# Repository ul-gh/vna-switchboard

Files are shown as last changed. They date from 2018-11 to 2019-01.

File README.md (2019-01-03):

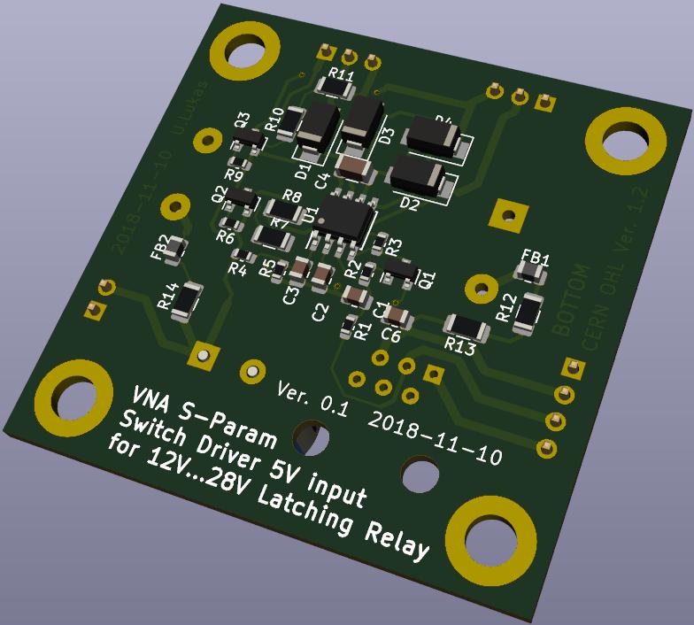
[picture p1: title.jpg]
Title Image


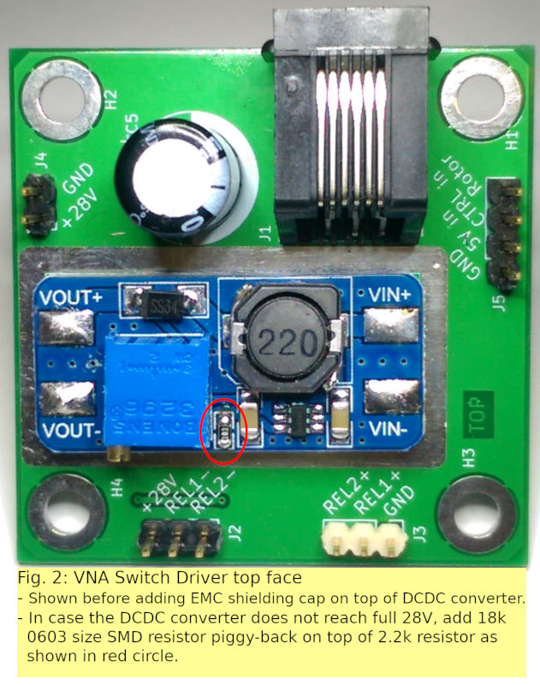
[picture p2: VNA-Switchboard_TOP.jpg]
Image VNA-Switchboard TOP face


# VNA-Switchboard FAN3241
KiCad project files for PCB driving a 12V...28V latching relay
from a single 5V voltage source, control is a high/low input signal.

Using an MT3608 step-up DCDC converter input current-limited
to less than 100 mA, timing and protection circuitry integrated
into FAN3241 driver IC and RF/EMC shielding provision for the
step-up coverter, this is designed for driving the direction
switch of a VNA S-parameter test set.

The input is a 6P6 western socket pinning compatible to the
DG8SAQ VNWA3. When this input is connected, no additional power
supply or control signals are required.

Schematic PDF: [VNA-Switchboard_FAN3241.pdf](VNA-Switchboard_FAN3241.pdf)

Additional instructions: Most if not all MT3608 DCDC converter boards sold
today require the following bug fix if medium output voltages are to be set:

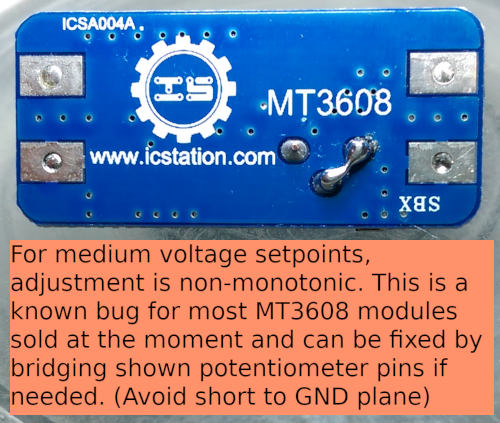
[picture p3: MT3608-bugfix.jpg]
MT3608 bug fix


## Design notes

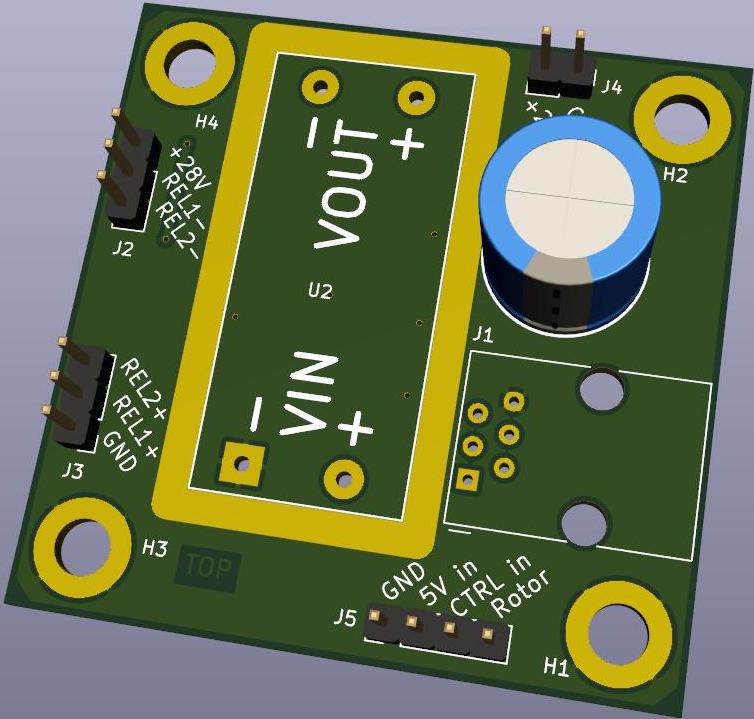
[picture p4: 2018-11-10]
preview2.jpg

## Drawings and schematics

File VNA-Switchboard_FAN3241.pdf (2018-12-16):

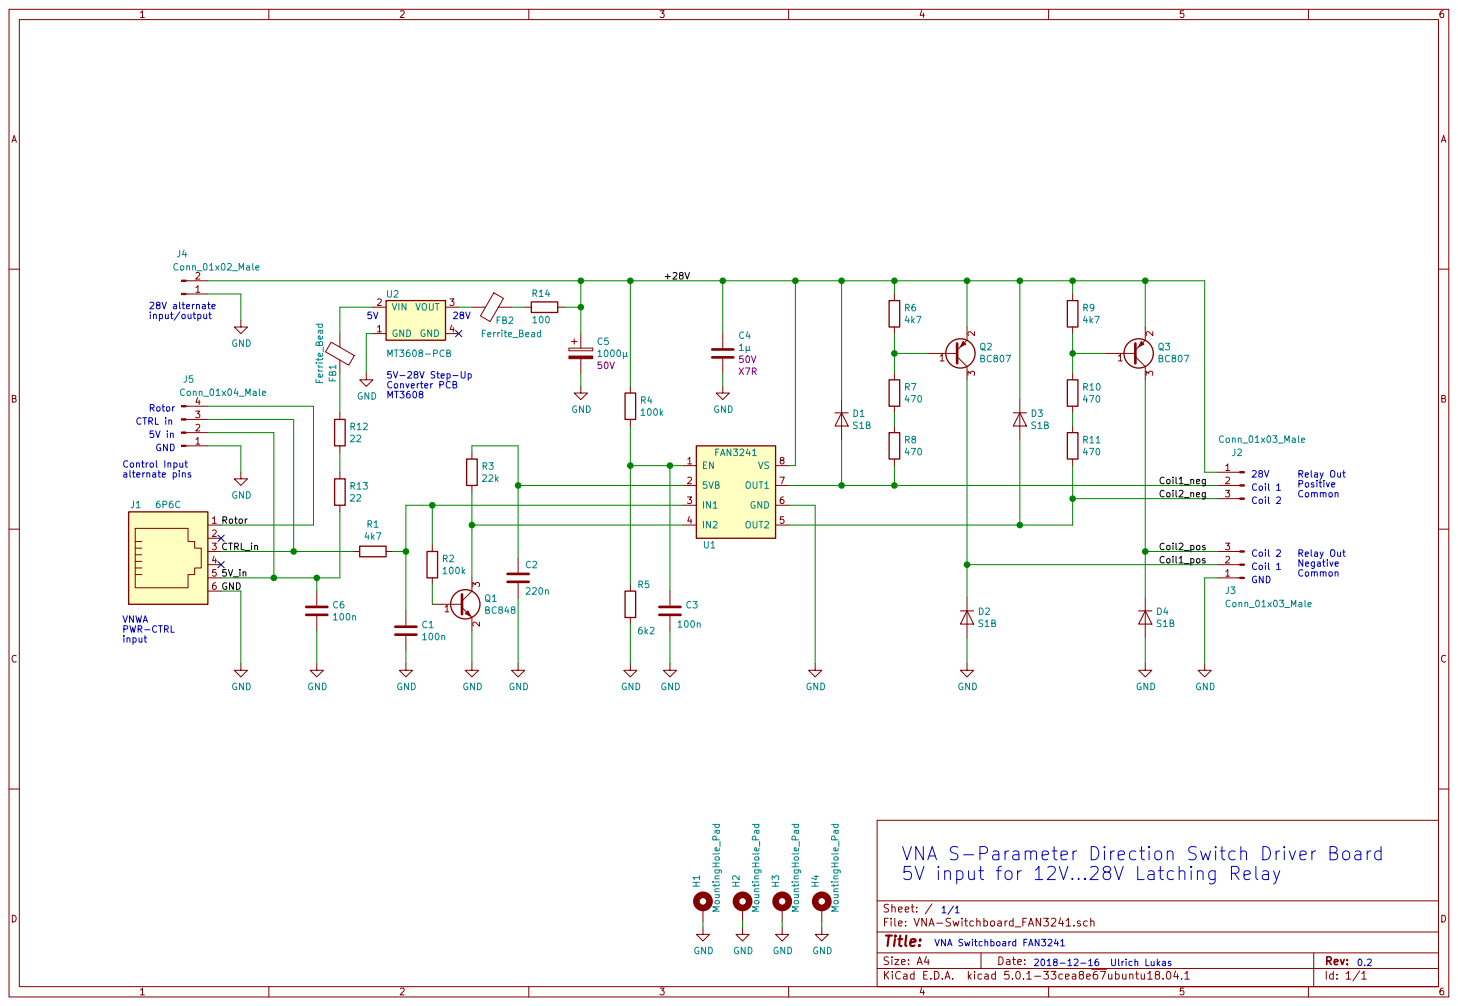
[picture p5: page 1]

5V input for 12V...28V Latching Relay

File: VNA-Switchboard_FAN3241.sch Sheet: /
Id: 1/1 Title:

2018-12-16 Ulrich Lukas VNA Switchboard FAN3241

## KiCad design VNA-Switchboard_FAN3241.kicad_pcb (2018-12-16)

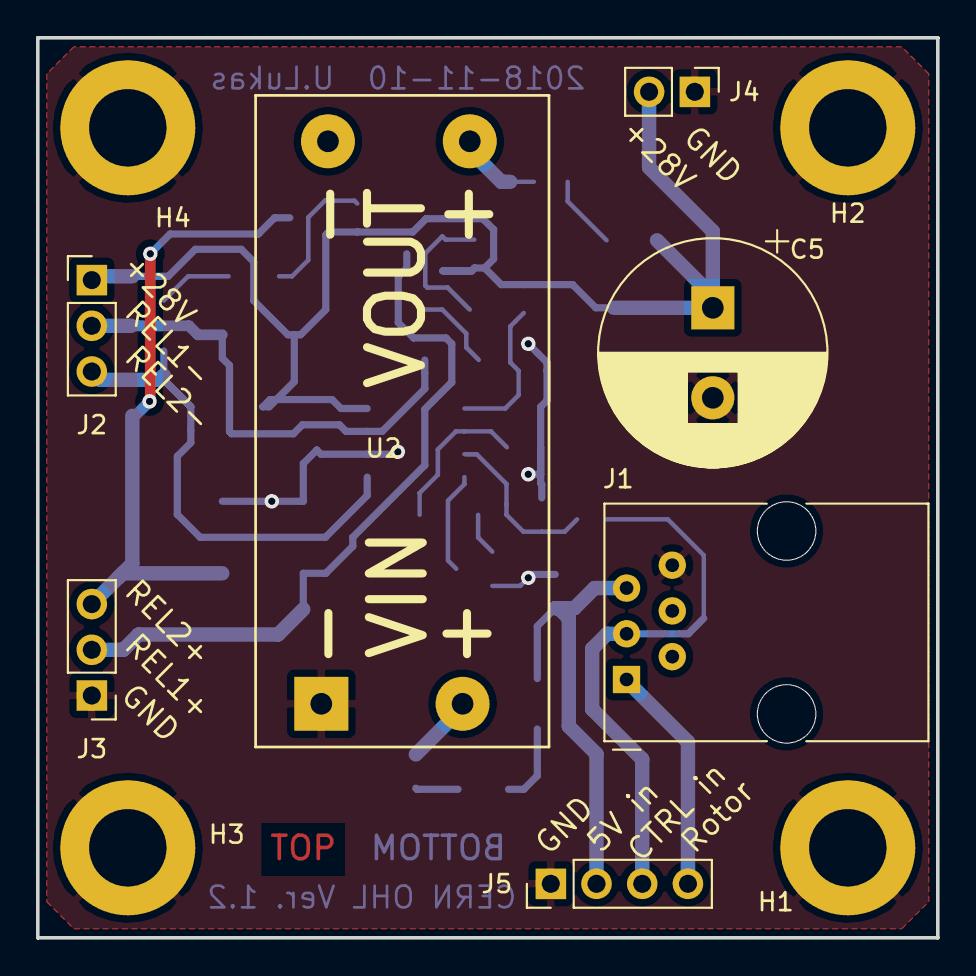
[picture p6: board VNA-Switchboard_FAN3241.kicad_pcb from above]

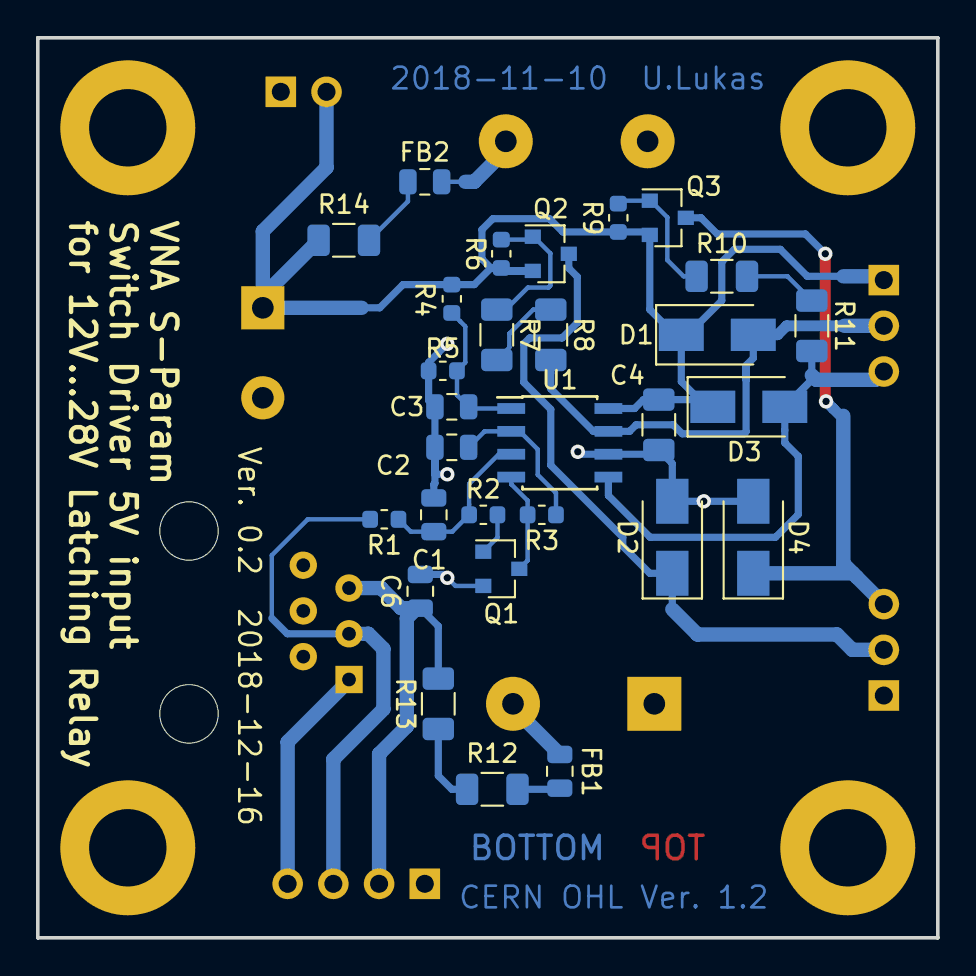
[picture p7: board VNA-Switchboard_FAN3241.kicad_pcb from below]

Board: 2 copper layers, 50.0 x 50.0 mm, 40 parts (29 on the bottom side), 23 nets.

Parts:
C1, C3, C6: 100n; C_0805_2012Metric
C2: 220n; C_0805_2012Metric
C4: 1µ; C_1206_3216Metric
C5: 1000µ; CP_Radial_D12.5mm_P5.00mm
D1, D2, D3, D4: S1B; D_SMA
FB1, FB2: Ferrite_Bead; L_0805_2012Metric
H1, H2, H3, H4: MountingHole_Pad; MountingHole_4.3mm_M4_DIN965_Pad
J1: 6P6C; RJ12_Amphenol_54601
J2, J3: Conn_01x03_Male; PinHeader_1x03_P2.54mm_Vertical
J4: Conn_01x02_Male; PinHeader_1x02_P2.54mm_Vertical
J5: Conn_01x04_Male; PinHeader_1x04_P2.54mm_Vertical
Q1: BC848; SOT-23
Q2, Q3: BC807; SOT-23
R1, R6, R9: 4k7; R_0603_1608Metric
R2, R4: 100k; R_0603_1608Metric
R3: 22k; R_0603_1608Metric
R5: 6k2; R_0603_1608Metric
R7, R8, R10, R11: 470; R_1206_3216Metric
R12, R13: 22; R_1206_3216Metric
R14: 100; R_1206_3216Metric
U1: FAN3241; SOIC-8_3.9x4.9mm_P1.27mm
U2: MT3608-PCB; MT3608_Step-Up_Converter_PCB

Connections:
/5V_in: C6.1, J1.5, J5.2, R13.2
/+28V: C4.1, C5.1, D1.1, D3.1, J2.1, J4.2, Q2.2, Q3.2, R4.1, R6.1, R9.1, R14.2, U1.8
/CTRL_in: J1.3, J5.3, R1.2
/Coil1_neg: D1.2, J2.2, R8.2, U1.7
/Coil1_pos: D2.1, J3.2, Q2.3
/Coil2_neg: D3.2, J2.3, R11.2, U1.5
/Coil2_pos: D4.1, J3.3, Q3.3
/Rotor: J1.1, J5.4
GND: C1.2, C2.2, C3.2, C4.2, C5.2, C6.2, D2.2, D4.2, H1.1, H2.1, H3.1, H4.1, J1.6, J3.1, J4.1, J5.1, Q1.2, R5.2, U1.6, U2.1
unnamed: C1.1, R1.1, R2.1, U1.3
unnamed: C2.1, R3.1, U1.2
unnamed: C3.1, R4.2, R5.1, U1.1
unnamed: FB1.1, R12.1
unnamed: FB1.2, U2.2
unnamed: FB2.1, R14.1
unnamed: FB2.2, U2.3
unnamed: Q1.1, R2.2
unnamed: Q1.3, R3.2, U1.4
unnamed: Q2.1, R6.2, R7.1
unnamed: Q3.1, R9.2, R10.1
unnamed: R7.2, R8.1
unnamed: R10.2, R11.1
unnamed: R12.2, R13.1

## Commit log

2018-11-10 Initial Version 0.1
    [VNA-Switchboard_FAN3241.kicad_pcb, VNA-Switchboard_FAN3241.sch]
2018-11-10 Added PDF schematic and top side preview image
2018-11-11 Default view changed
    [VNA-Switchboard_FAN3241.kicad_pcb]
2018-12-16 R4 and R5 wrong value. C5 larger value optinal.
    [VNA-Switchboard_FAN3241.kicad_pcb, VNA-Switchboard_FAN3241.sch]

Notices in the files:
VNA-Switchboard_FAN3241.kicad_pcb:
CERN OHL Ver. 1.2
